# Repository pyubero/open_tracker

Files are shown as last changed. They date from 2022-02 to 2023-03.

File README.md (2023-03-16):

# open_tracker

The `open_tracker` is a suite of Computer Vision scripts that automatizes the recording and analysis of *C. elegans* behavioral videos, although it can be used with any animal/object in general. It was developed by Pablo Yubero at the Centro Nacional de Biotecnología (CSIC) in Madrid, Spain for the completion of the doctoral thesis entitled "Trade-offs in the architecture and predictability of complex phenotypes" funded by the Ministerio de Ciencia e Innovación and the Europen Social Fund.

<p align="center">
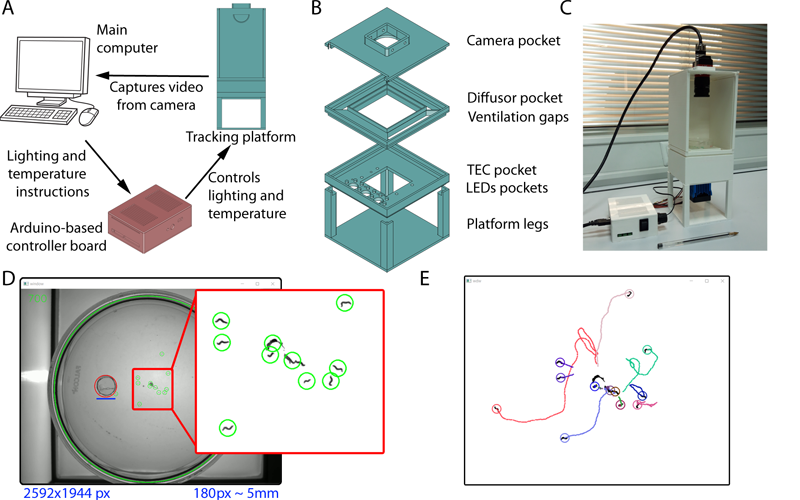
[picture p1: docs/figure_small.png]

</p>

## Protocol :bug:
The intended use of these scripts is sequential. I here include a brief description of each script.

* `s0_Recording.py` On execution, it will show a live preview of your camera stream, thus the user can easily adjust the lighting conditions, the focus of the camera and all that jazz before pressing "R" and starting to record a video. If the video is too long, the video will be recorded in fixed-length chunks (limits can be tuned). 
* `s1_Blob_extraction.py` On execution it will load a video, and do all the preprocessing to then export a pickle file with all the moving blobs found. If the results are not satisfactory, the user can easily tune all preprocessing steps. 
* `s2a_Ref_contour_finder.py` As worms are kind of small (to maximize field of view), they can sometimes be mixed up with noise. This scripts is aimed at identifying a model worm to later reliably identify worms in every frame. On execution you will be presented with the first frame and its blobs, you can loop through them until finding the "ideal worm" that will be used as reference. Once found, press "S" to save it, then "Q" to exit.
* `s2b_Metric_selection.py` On execution, it will analyse all blobs in the first frames of the videos to build a model (Gaussian Mixture) to automatically set up a metric that guarantees the correct identification of most (and best) worms.
* `s3_Tracking.py` This is the real deal, it will use all the previous data to finally export an .npz matrix  of size (n\_worms x n\_frames x 2) that stores the coordinates (x and y) of all worms in all frames, filled with np.nan's when necessary. 

## Materials and methods :telescope:
#### Image processing
For image processing we strongly recommend  using OpenCV, although we seldom use our own algorithms. OpenCV includes for example automatic background subtraction, complex shape/animal recognition, brightness and contrast control, thresholding, image denoising...

#### Tracking algorithm
The tracker is able to track a variable number of worms in any video, thus a predefined number is not necessary. At frame t+1, identity matching proceeds in four steps.

1. All worms present in frame t are matched by a progressive scanning algorithm and a Kalman filter, this facilitates the identification of worm forking, that is,when two initially superimposed worms separate).
2. The remaining worms are linked to blobs that are already in use to facilitate the identification of overlapping worms, that is, when two initially distinct worms touch each other). 
3. The remaining unused blobs are then candidates to be newly identified worms. Those are selected according to some user-defined rule, in our case, we used similarity of both Hu's invariant image descriptors and worm size.
4. (Optional) The tracking of some worms can be stopped. This can be used when worms can escape the field of view. 

#### Environmental control 
The environmental conditions are controlled by an Arduino Nano on a homemade controlling board. The board supports 3x high power LEDs (we are currently using the triplet 400nm, 650nm and 400K); a 60W Thermoelectric Couple that works in both heat/cold directions; 2x small fans to dissipate heat and accelerate cooling; automatic zoom/focus via two stepper motors (currently unused); two small indicating bicolor LEDs; and a temperature sensor.

#### Recording platform
The recording platform and a case for the controlling board were both designed using FreeCAD. Original and print-ready .stl files are available in the `/docs/models_3d` folder. All pieces were printed nicely using either ABS or PLA by standard protocols in a Ultimaker 2 printer. We strongly recommend using black (mate if possible) plastic to prevent leaks of light and internal reflections.

#### Webcam support
In this repo you will find support for two types of webcam, those that use the Universal Video Class (UVC) and those that rely on AppliedVision's Vimba SDK. While UVC works using OpenCV, AppliedVision's cameras need the Vimba SDK for Python installed.

There are different classes to interact with each type called `/pytracker/myCamera_UVC` and `/pytracker/myCamera_Alvium`, be sure to use the most appropiate one. These classes have a few fundamental functions: `open()`,`close()`,`snapshot()`,`start_preview()`, `get()`, and `set()`, you can find more info on how to use them in the scripts contained in the `\test` folder.

## Reference :bell:
Should you use this repo in any way, please reference the PhD thesis: 

Yubero P. (2022). _Trade-offs in the architecture and predictability of complex phenotypes_. (Doctoral dissertation, Universidad Autónoma de Madrid, Spain). Retrieved from repositorio.uam.es

## Contact and license :incoming_envelope:
If you have any issue with this repo please contact me through github rather than email. Feel free to ask for updated versions, or latest developments.

This code is distributed under an MIT license.

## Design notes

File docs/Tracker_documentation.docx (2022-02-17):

Worm Tracker Documentation

# Introduction

# Software

# Hardware

An arduino is a microprocessor that is able to perform simple tasks like turning on/off switches and measuring voltages. We will use this to precisly control three high power leds for illumination, a Peltier element (thermoelectric couple) and a couple of fans for temperature control and, a motor driver to digitally control the focus of the camera. Also, we use the Firmata protocol to establish a robust communication between the Arduino and a computer. In the following sections you can find a detailed description of why and how the controller board was designed.

### Arduino (in general)

We use an Arduino Nano board, because it has enough digital pins to control everything we need, it can be based on either ATmega168 or ATmega328. In general, it features several modules that will be described in the following sections namely: thermistor, manual potentiometer, led lighting, temperature control, stepper motor control and signaling leds (see Table X)

Pulldown resistors. When the Arduino is turned on, all pins are turned as input by default. During this time, digital pin values are floating and are neither high nor low. After a few seconds, all pins are set to output low [DO IN SOFTWARE]. To avoid this transient response, we have added to every digital output pin a pulldown resistor to keep this from happening.

<W> The Arduino board must necessarily share the ground connection with the external power supply at all times.

Number | Function | Pins | Comments
1 | Temperature sensor | A0 | Analog thermistor
1 | Potentiometer | A1 | Manual action
3 | Dimmable high power leds | D9, D10 and D11 | 1W, 350mA
1 | One-way TEC control (60W) | D5 | w/ MOSFET
1 | Two-way TEC control (60W) | D5 and D6 | w/ motor driver
1 | Fan control | D2 | Two fans in parallel
1 | Stepper motor control | D12 and D13 | Used to focus
1 | Signaling leds | D7 and D8 | Bicolor

Table 1. Main board functions

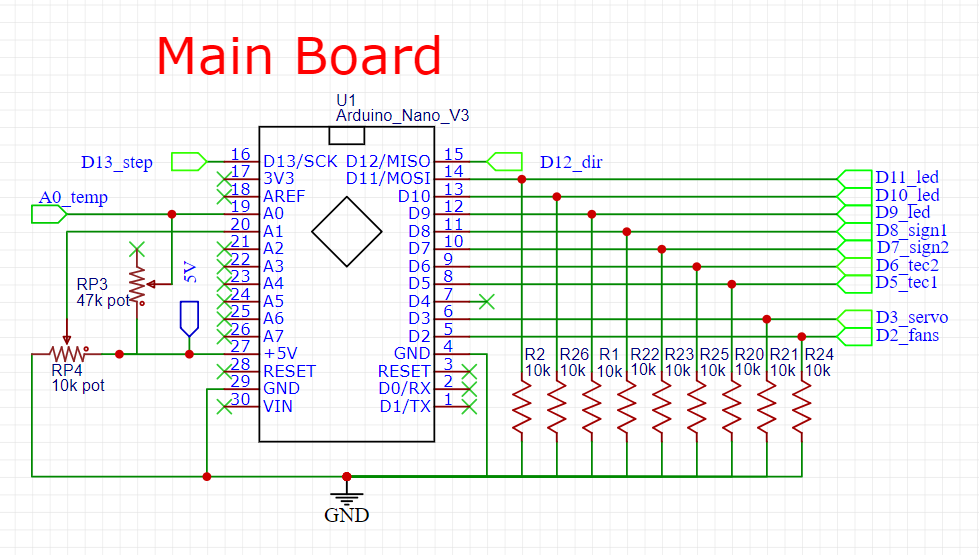
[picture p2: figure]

### Temperature sensor

We use a thermistor called an “3950 NTC Thermistor Temperature Sensor 10K 1%” with a beta parameter equal to 3380K +/- 1%. This device is a resistor whose value depends strongly on its temperature. As it is an N(egative)TC, when the temperature raises, the resistance falls. To compute the temperature we need two equations: one to compute the temperature of the probe from its resistance, and another to compute the resistance from an analog voltage (as measured by the Arduino).

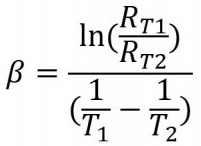
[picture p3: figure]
NTC Thermistor Beta Equation

First, the equation to the left can be rearranged to provide a resistance value (R_T2) given a temperature (T2) and a reference resistance (R_T1) at a reference temperature (T1). Note that temperatures are in Kelvin. The reference temperature T1 is usually 25ºC, or 298K. Its resistance at such temperature R_T1 is about 10kOhm, and the beta constant is said to be 3380 1/K. Plug everything into the equation and you can obtain T2 as a function of R2.

T_2 =((ln((R_2)/(R_1)))/β+1/(T_1))+293

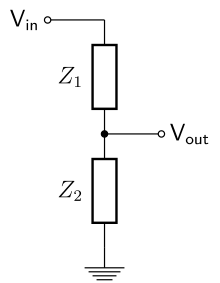
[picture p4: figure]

To measure R2, we use a voltage divider as the schematic in the left. Vin is a constant reference voltage (5V in our case), Z1 and Z2 are two resistors and Vout is the voltage measured at that point (A0 in our case). Either Z1 or Z2 can be a reference resistor and the other is the thermistor (as a variable resistor, R2 in the previous paragraph). The voltage measured in Vout, will be: Vout = Vin*(Z2/[Z1+Z2]). From this equation, one can obtain a function that returns the variable resistance R2 as a function of the measured voltage Vout. Depending on your reference resistor, temperature will be measured more accurately in a certain range of temperatures. We recommend a reference resistance equal to the NTC resistance at around 20ºC to maximize precision at this temperature. On top of this, Arduino does not directly measure Vout, but rather, the fraction Vout/Vin in 8bit. This means that when reading A0=0 then Vout=0V and when A0=256 then Vout=Vin. We finally have:

R_2 =R_(ref) ((V_(out))/(V −V_(out)))=R_(ref) ((A0)/(256−A0))

In our case we have used the scenario where Z1 is a 47kOhm variable resistor and Z2=R2. With this, we can adjust Z1 for improved temperature accuracy.

Note that the previous is a general procedure, but in our case, as we use the Firmata protocol to es

### Potentiometer (manual)

We have added a potentiometer that can be turned manually to make it easy to adjust the output of any pin. The goal was to easily dim the principal led, but other functions can be set in the myArduino class. The working principle is that of the voltage divider as in the previous section, in this case however Z1+Z2 is fixed to the potentiometer’s maximum value (10kOhm in our circuit).

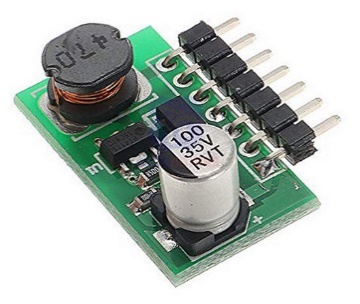
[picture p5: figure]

### Dimmable high power leds

The Arduino board cannot output over 40mA in a single pin, hence, to drive high power leds that require 350mA we need a led driver. We use a cheap module that allows to easily dim the led’s brightness with a PWM signal. A PWM signal is similar to an analog voltage that can take a continuum of values, in this way, the higher the voltage, the more intense the lighting.

For each high power led, we use either digital pins D9, D10 or D11. We have included a 4.7 kOhm resistor to limit the current provided by the Arduino to about 1mA. Also, we have tuned the fermata script to increase the frequency of the PWM signals driving the leds to avoid resonance with the camera FPS.

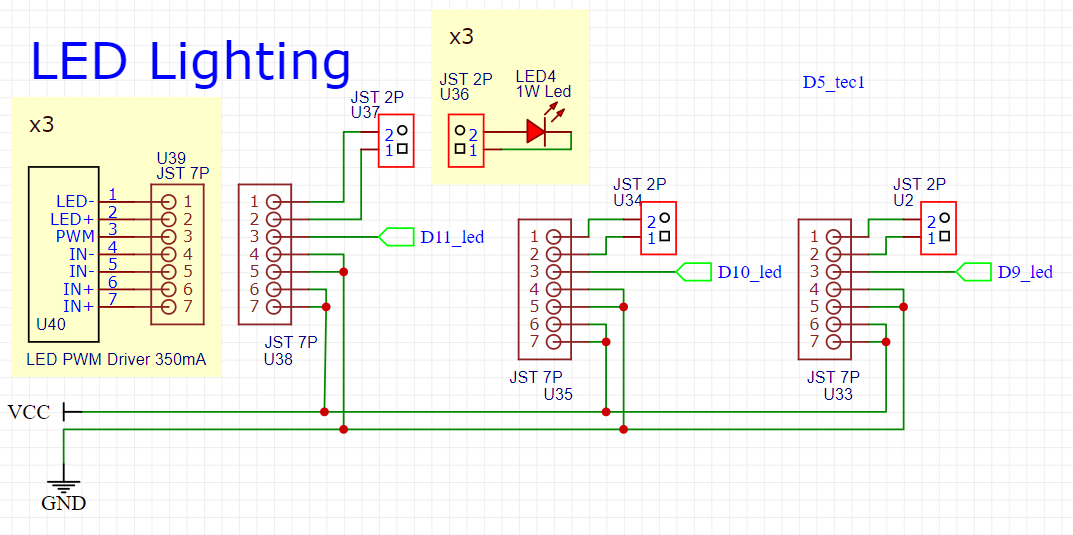
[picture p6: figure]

### TEC control

To control the temperature inside the chamber we use a “thermoelectric couple”, or TEC, also known as “Peltier element”. This device can cool down one of its faces and heat up the other while current is flowing. If the heat of the hot side is well dissipated, then the cold side can reach very low temperatures.

<W> It is very important that there is thermal paste between the TEC and both heat dissipators.

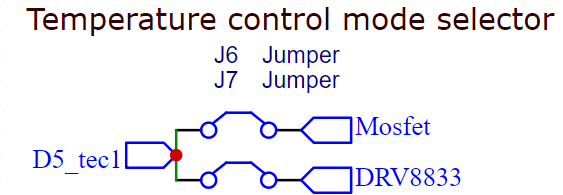
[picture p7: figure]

In our case we use a Peltier element rated max at 12V or 5A. The measured resistance is indeed about 2.5 ohm, but it can vary largely with temperature (or current). There is no easy and perfect way to control a TEC, so we propose two options: a one-way control that is only able to cool down the chamber (to hopefully very low temperatures) and a two-way control that is also able to heat up the chamber.

<W> To select between one- or two-way modes, we added a pair of jumpers. ONLY one should always be connected.

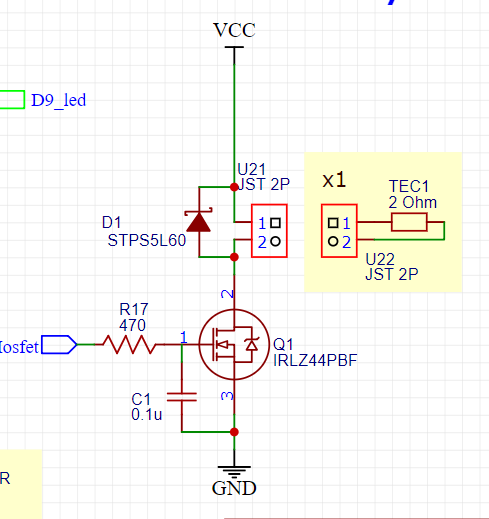
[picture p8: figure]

#### One-way control of the TEC

To drive the TEC at different voltages we will use a logic-level, switching MOSFET. By doing this, we can apply a PWM signal to the MOSFET’s gate to quickly turn it on/off so that the TEC sees a fraction of the total input voltage. If the duty cycle is set to 100% then around 4.5A will be going through the TEC providing a large cooling power but not efficiently! Recall that resistive power losses go as the current squared.

We chose the IRLZ44 due to its large voltage headroom (60V) for possible switching spikes and for its low R_DS=28mOhm. In the worst case scenario, 5A will go through the MOSFET, which will need to dissipate <1W. Even so, we can add a TO-220 dissipator. In the circuit we simply added a 470 Ohm resistor between the Arduino pin and the gate to limit the current to 10mA (and to protect the Arduino from back emf during switching). As the TEC is a resistive load, we shouldn’t need a flyback diode, however we attached one just in case parasitic inductance causes problems. We also added a decoupling cap between the gate and the ground.

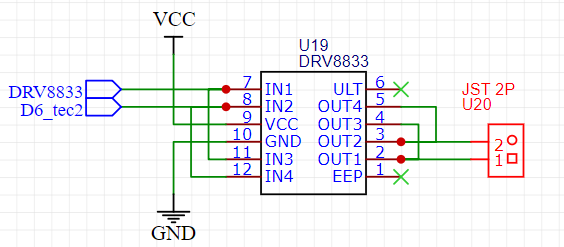
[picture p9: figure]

#### Two-way control of the TEC

To drive the TEC in both cold and hot modes, we must use the H-bridge of a motor driver. We used DRV8833 because of its relatively high output power (up to 1.5A per channel, so a total max of 3A which is less than the 4.5A of the one-way MOSFET). The module already includes different types of protection (over-temperature, over-current…) so the pinout is pretty straightforward. Depending on the IN1 and IN2 values cooling/heating modes are toggled. In our case IN1/3 are set by D6 while IN2/4 by D5. Remember that to turn off the Peltier module BOTH D5 and D6 need to be set LOW or HIGH.

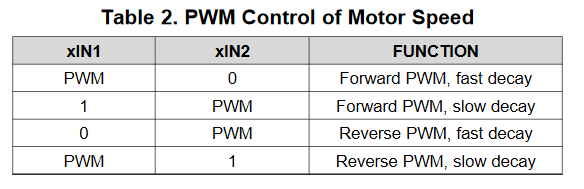
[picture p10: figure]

### Fan control

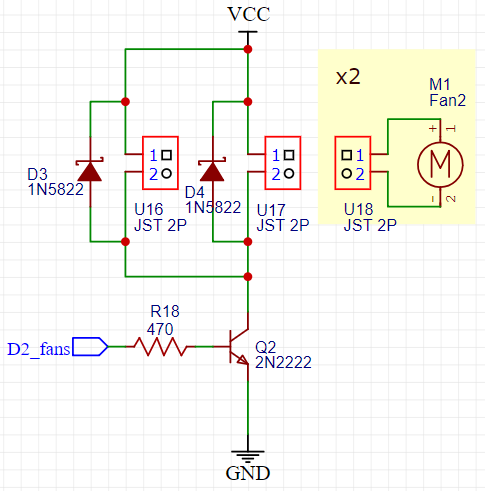
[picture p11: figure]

There should be TWO fans, one for the hot side and another for the cold side because i) the fan on the cold side will improve cooling power to the chamber, and ii) the fan on the cold side might be needed if the TEC direction is reversed and it starts heating the chamber.

Both fans are controlled with a 2N222 transistor as the necessary current is about 400mA (300mA from the large fan and an extra 100mA from the smaller one inside the chamber). Although fans have supposedly built-in flyback diodes, we added a pair of 1N5822 Schottkys (although they won’t be PWMed) for back EMF protection. There is also a 470 Ohm between the Arduino pin and the transistor’s base to limit the current to 10mA. With an hFE of 40 it results in about 400mA max across the collector and emitter. This transistor won’t be PWMed but rather we will fully turn it on/off for long periods of time.

### Stepper motor control

We add the possibility of controlling a stepper motor as an electronic camera focuser. However only x3 2P connectors are provided in the board as the A4988 stepper driver wouldn’t fit. Hence this optional module should be mounted on an external board.

Its connection is straightforward following any stepper tutorial. Mainly, we need a power connection (to power the motor), a logic power connection (to power the module) and two control signals: STEP and DIRECTION. We also propose to use three jumpers to select microstepping operation. Finally, a decoupling capacitor of 100nF is added between Vmot and GND.

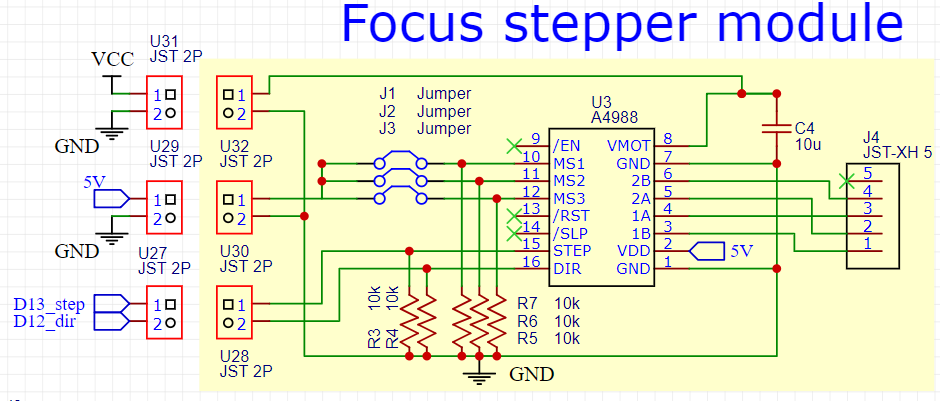
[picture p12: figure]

https://www.ti.com/lit/ds/symlink/drv8873-q1.pdf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

https://www.ti.com/lit/an/slua979a/slua979a.pdf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

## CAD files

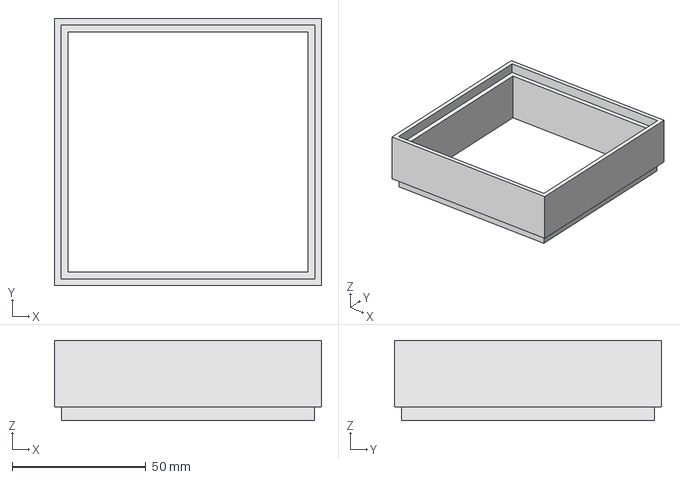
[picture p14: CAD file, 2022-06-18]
docs/models_3d/parametrized.FCStd
100.0 x 100.0 x 30.0 mm

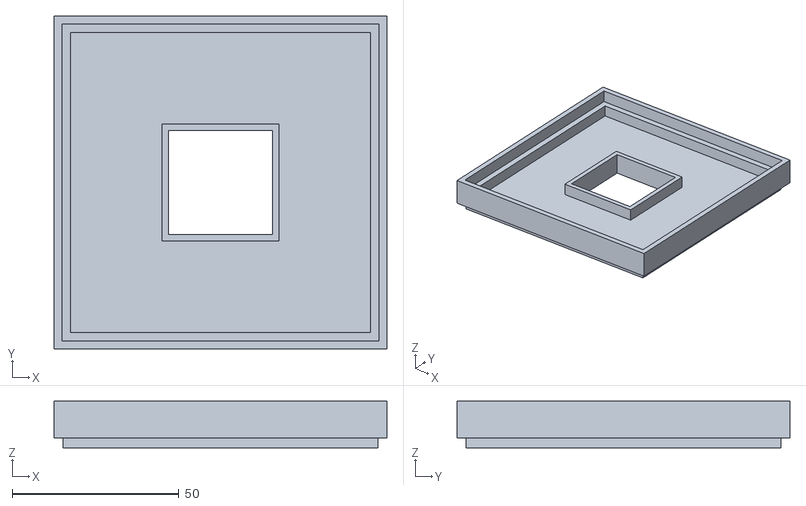
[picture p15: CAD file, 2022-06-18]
docs/models_3d/stl-files/parametrized-base_ledmatrix.stl
100.0 x 100.0 x 14.0

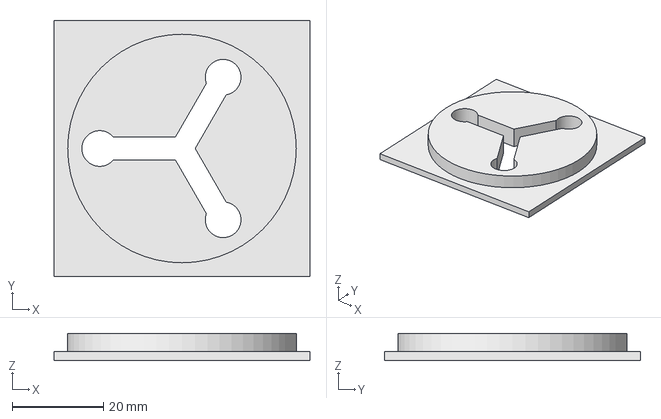
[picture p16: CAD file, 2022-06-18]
docs/models_3d/arenas.FCStd
56.0 x 56.0 x 6.00 mm

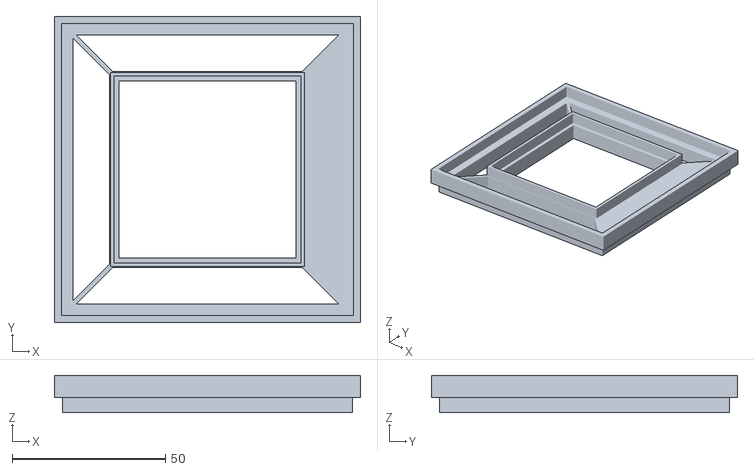
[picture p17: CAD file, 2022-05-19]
docs/models_3d/stl-files/parametrized-plate_base_v0.stl
100.0 x 100.0 x 12.1

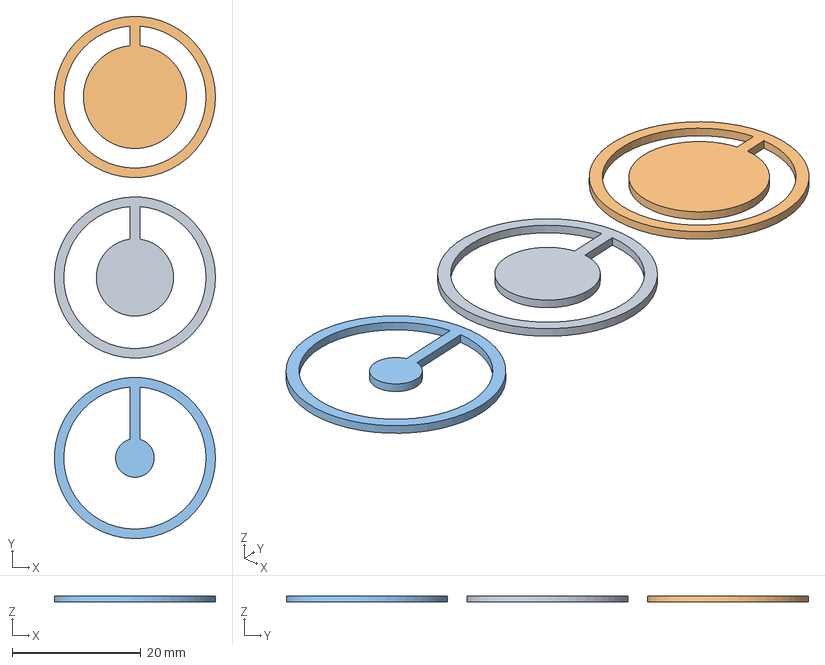
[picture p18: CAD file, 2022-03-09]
docs/models_3d/phase_shifters.FCStd
25.0 x 81.0 x 1.00 mm
shifter_medium
shifter_large
shifter_small

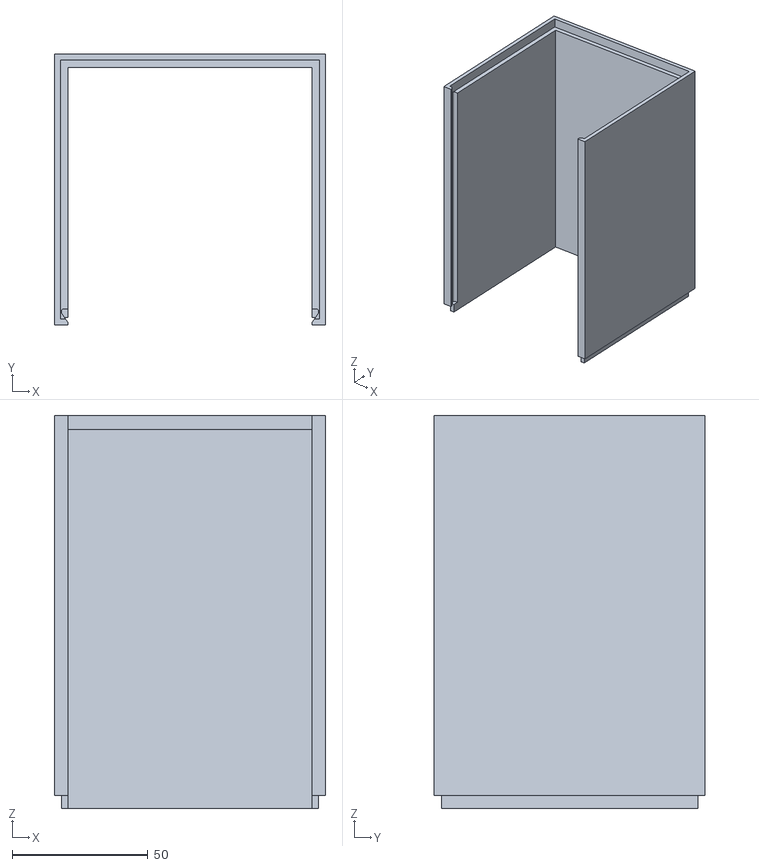
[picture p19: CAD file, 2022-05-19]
docs/models_3d/stl-files/Finished/parametrized-3walls_v1.stl
100.0 x 100.0 x 144.9

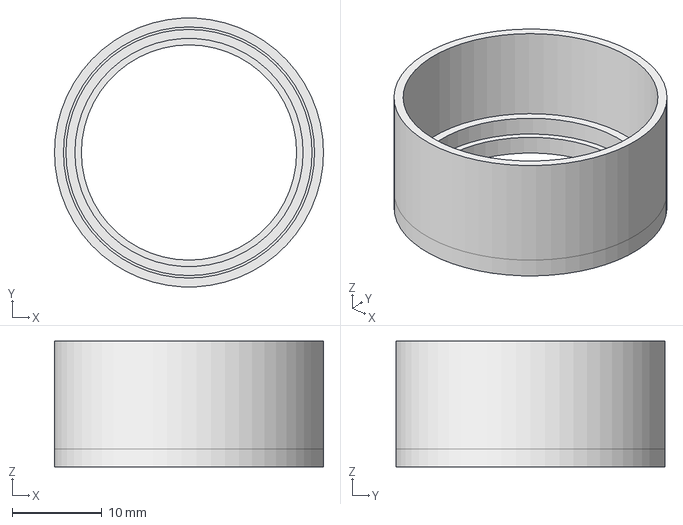
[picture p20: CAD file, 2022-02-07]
docs/models_3d/filter_holder.FCStd
30.0 x 30.0 x 14.0 mm

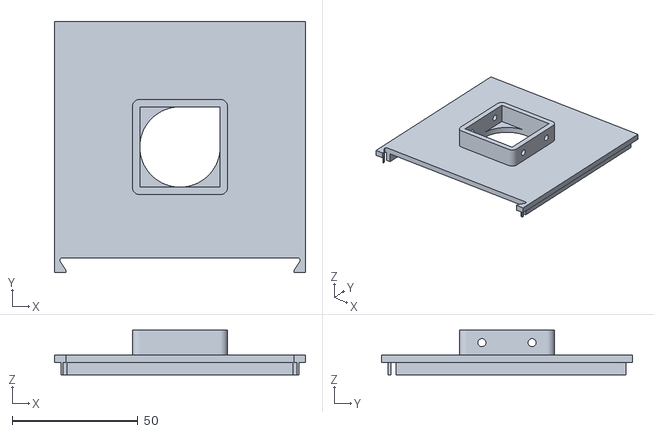
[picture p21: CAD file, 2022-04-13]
docs/models_3d/stl-files/Finished/parametrized-tapa_alvium_v1.stl
100.0 x 100.0 x 17.9

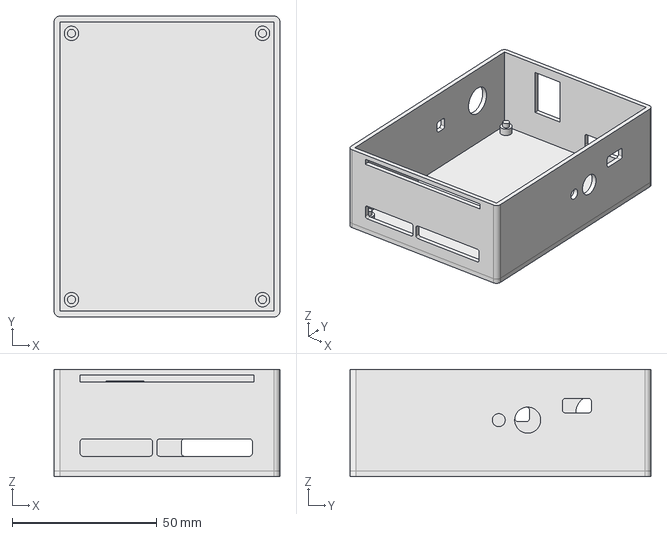
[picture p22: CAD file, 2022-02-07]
docs/models_3d/board_enclosure.FCStd
78.0 x 104.0 x 37.0 mm

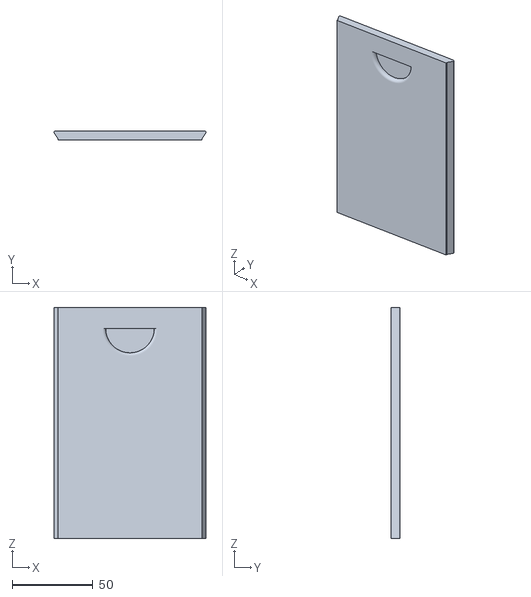
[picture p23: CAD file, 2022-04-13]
docs/models_3d/stl-files/Finished/parametrized-door.stl
94.0 x 5.85 x 143.0

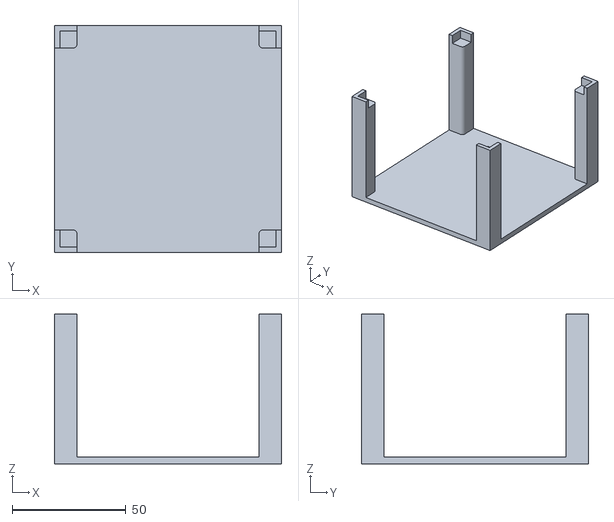
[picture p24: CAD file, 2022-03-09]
docs/models_3d/stl-files/Finished/parametrized-base_legs.stl
100.0 x 100.0 x 66.0

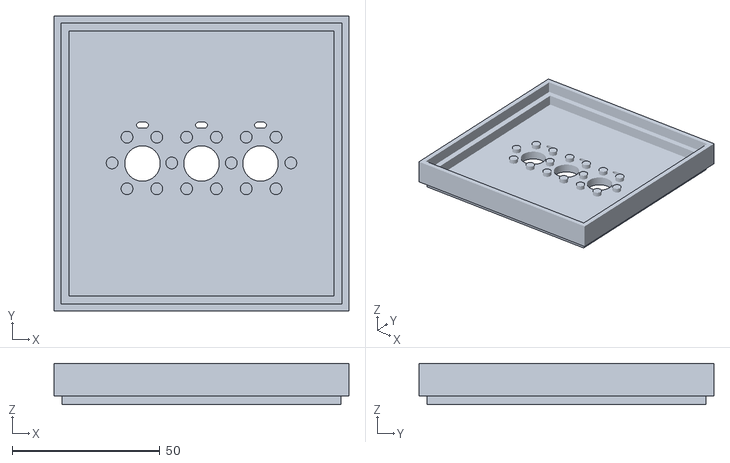
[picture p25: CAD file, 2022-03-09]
docs/models_3d/stl-files/Finished/base_lighting.stl
100.0 x 100.0 x 14.0

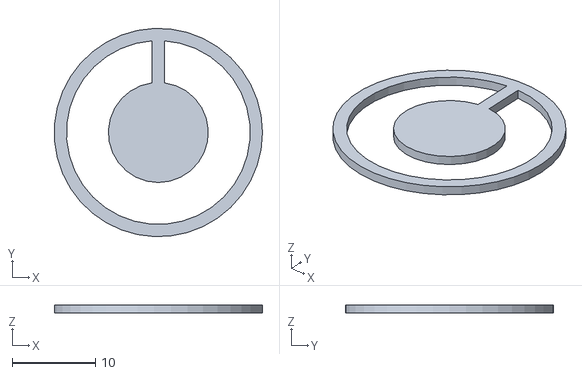
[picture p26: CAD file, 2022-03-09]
docs/models_3d/stl-files/Finished/phase_shifters-shifter_medium.stl
25.0 x 25.0 x 1.00

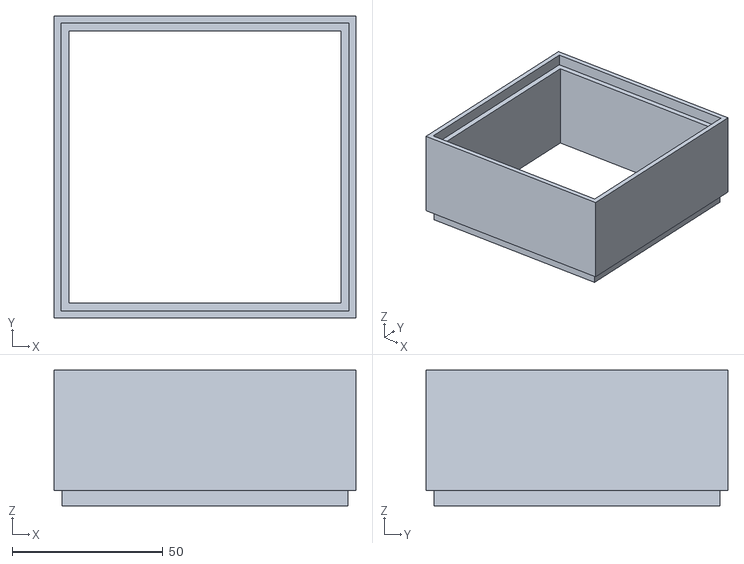
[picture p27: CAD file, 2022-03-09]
docs/models_3d/stl-files/Finished/parametrized-4walls_45mm.stl
100.0 x 100.0 x 45.0

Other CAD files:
docs/models_3d/stl-files/Finished/parametrized-4walls_30mm.stl
docs/models_3d/stl-files/Finished/arenas-2-decision_making.stl
docs/models_3d/stl-files/Finished/phase_shifters-shifter_small.stl
docs/models_3d/stl-files/Finished/tapon_led_update1.stl
docs/models_3d/stl-files/Finished/phase_shifters-shifter_large.stl

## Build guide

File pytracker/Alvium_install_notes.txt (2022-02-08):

Step 1.
Go to Allied Vision Download center to download the SDK.
In our case we installed v5.1.0 for Windows from:
	https://www.alliedvision.com/en/support/software-downloads/

Install on: C:\Program Files\Allied Vision\Vimba_5.1
and examples in : C:\Users\Public\Documents\Allied Vision\Vimba_5.1

And BE SURE to install the Python Api, although we recommend a complete installation of the SDK.

Step 2.
Go the C:\Program Files\Allied Vision\Vimba_5.1\VimbaPython\Documentation
and follow the manual's instructions for installing the python package.

Basically they say to execute from a (conda) terminal in the sources folder the following command: python -m pip install .[numpy-export,opencv-export]

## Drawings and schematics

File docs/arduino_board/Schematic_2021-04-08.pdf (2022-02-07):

VIN 30 GND 29 RESET 28 +5V 27 A7 26 A6 25 A5 24 A4 23 A3 22 A2 21 A1 20 A0 19 AREF 18 3V3 17 D13/SCK 16

# Main Board

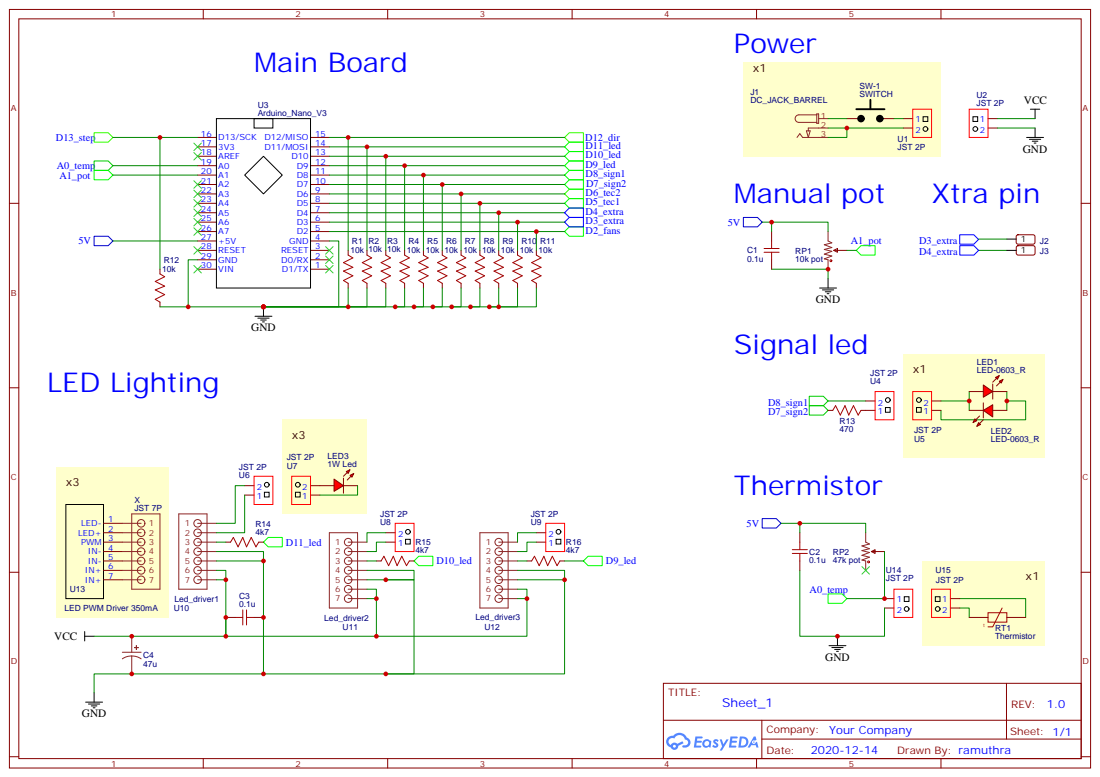
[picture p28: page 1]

# Focus stepper module

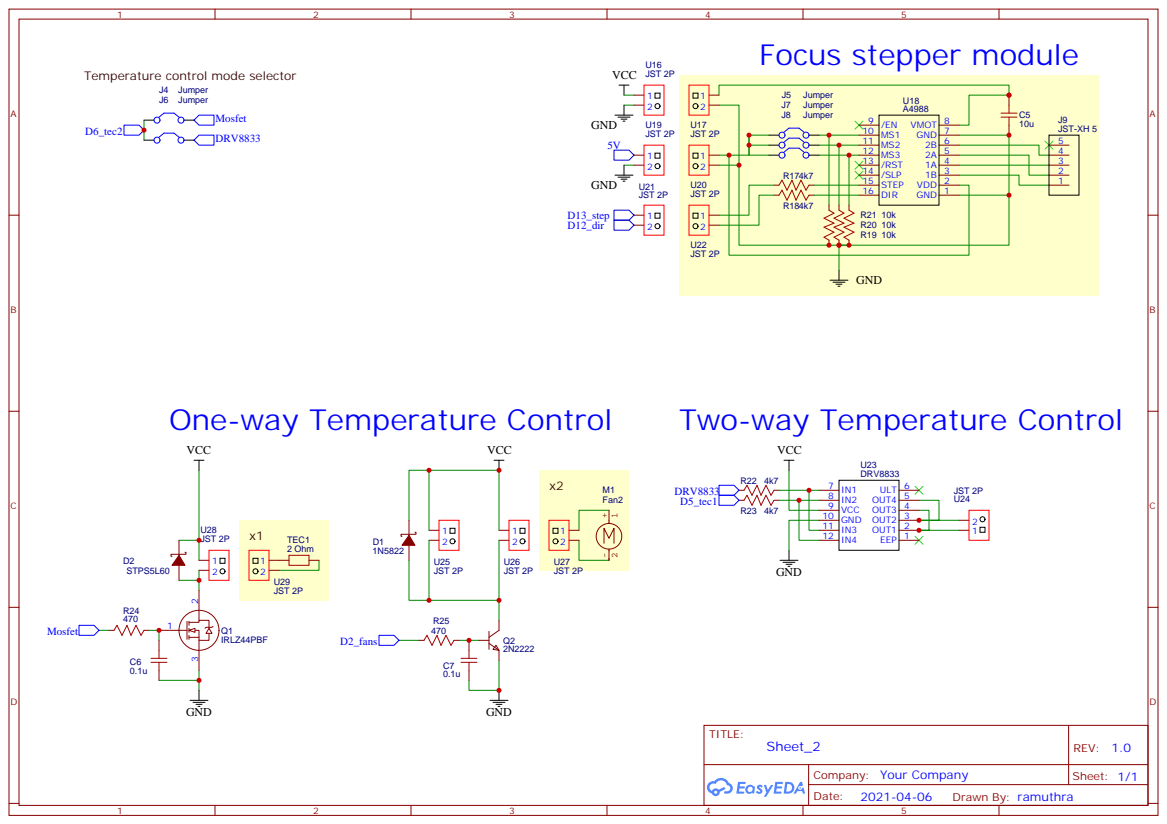
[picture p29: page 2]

Temperature control mode selector

One-way Temperature Control

Two-way Temperature Control

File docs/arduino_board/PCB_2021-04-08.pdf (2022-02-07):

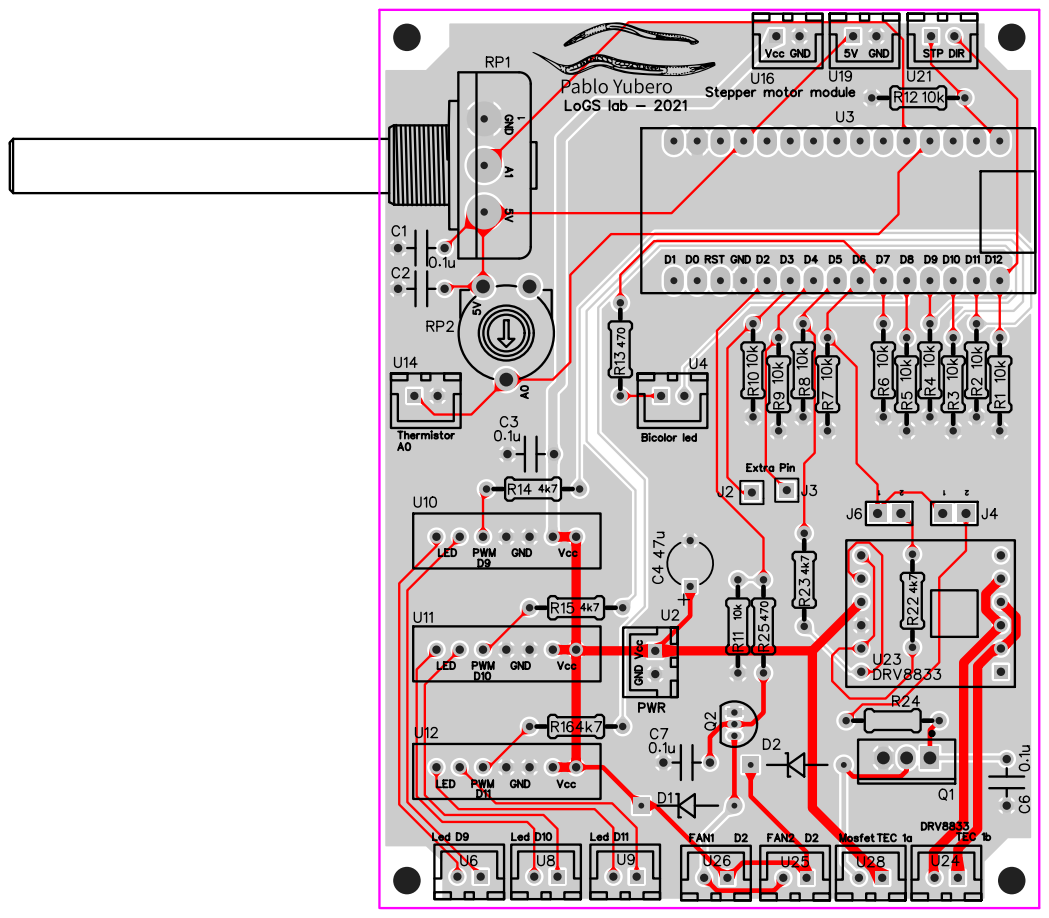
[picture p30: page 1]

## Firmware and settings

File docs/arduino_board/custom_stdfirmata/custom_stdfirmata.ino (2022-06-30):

/*
  Firmata is a generic protocol for communicating with microcontrollers
  from software on a host computer. It is intended to work with
  any host computer software package.

  To download a host software package, please click on the following link
  to open the list of Firmata client libraries in your default browser.

  https://github.com/firmata/arduino#firmata-client-libraries

  Copyright (C) 2006-2008 Hans-Christoph Steiner.  All rights reserved.
  Copyright (C) 2010-2011 Paul Stoffregen.  All rights reserved.
  Copyright (C) 2009 Shigeru Kobayashi.  All rights reserved.
  Copyright (C) 2009-2016 Jeff Hoefs.  All rights reserved.

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
  See file LICENSE.txt for further informations on licensing terms.

  Last updated August 17th, 2017

 This is a modified FIRMATA protocol. The only modifications being:
 1. The change of clock registers to allow faster PWM frequencies. 
 2. The change of serial Baudrate to minimize serial errors
 All changes reside in the ## SETUP ## section, around l. 750.

 - Pablo Yubero, January 2022 at the LoGS lab in Madrid.
*/

#include <Servo.h>
#include <Wire.h>
#include <Firmata.h>

#define I2C_WRITE                   B00000000
#define I2C_READ                    B00001000
#define I2C_READ_CONTINUOUSLY       B00010000
#define I2C_STOP_READING            B00011000
#define I2C_READ_WRITE_MODE_MASK    B00011000
#define I2C_10BIT_ADDRESS_MODE_MASK B00100000
#define I2C_END_TX_MASK             B01000000
#define I2C_STOP_TX                 1
#define I2C_RESTART_TX              0
#define I2C_MAX_QUERIES             8
#define I2C_REGISTER_NOT_SPECIFIED  -1

// the minimum interval for sampling analog input
#define MINIMUM_SAMPLING_INTERVAL   1


/*==============================================================================
 * GLOBAL VARIABLES
 *============================================================================*/

#ifdef FIRMATA_SERIAL_FEATURE
SerialFirmata serialFeature;
#endif

/* analog inputs */
int analogInputsToReport = 0; // bitwise array to store pin reporting

/* digital input ports */
byte reportPINs[TOTAL_PORTS];       // 1 = report this port, 0 = silence
byte previousPINs[TOTAL_PORTS];     // previous 8 bits sent

/* pins configuration */
byte portConfigInputs[TOTAL_PORTS]; // each bit: 1 = pin in INPUT, 0 = anything else

/* timer variables */
unsigned long currentMillis;        // store the current value from millis()
unsigned long previousMillis;       // for comparison with currentMillis
unsigned int samplingInterval = 19; // how often to run the main loop (in ms)

/* i2c data */
struct i2c_device_info {
  byte addr;
  int reg;
  byte bytes;
  byte stopTX;
};

/* for i2c read continuous more */
i2c_device_info query[I2C_MAX_QUERIES];

byte i2cRxData[64];
boolean isI2CEnabled = false;
signed char queryIndex = -1;
// default delay time between i2c read request and Wire.requestFrom()
unsigned int i2cReadDelayTime = 0;

Servo servos[MAX_SERVOS];
byte servoPinMap[TOTAL_PINS];
byte detachedServos[MAX_SERVOS];
byte detachedServoCount = 0;
byte servoCount = 0;

boolean isResetting = false;

// Forward declare a few functions to avoid compiler errors with older versions
// of the Arduino IDE.
void setPinModeCallback(byte, int);
void reportAnalogCallback(byte analogPin, int value);
void sysexCallback(byte, byte, byte*);

/* utility functions */
void wireWrite(byte data)
{
#if ARDUINO >= 100
  Wire.write((byte)data);
#else
  Wire.send(data);
#endif
}

byte wireRead(void)
{
#if ARDUINO >= 100
  return Wire.read();
#else
  return Wire.receive();
#endif
}

/*==============================================================================
 * FUNCTIONS
 *============================================================================*/

void attachServo(byte pin, int minPulse, int maxPulse)
{
  if (servoCount < MAX_SERVOS) {
    // reuse indexes of detached servos until all have been reallocated
    if (detachedServoCount > 0) {
      servoPinMap[pin] = detachedServos[detachedServoCount - 1];
      if (detachedServoCount > 0) detachedServoCount--;
    } else {
      servoPinMap[pin] = servoCount;
      servoCount++;
    }
    if (minPulse > 0 && maxPulse > 0) {
      servos[servoPinMap[pin]].attach(PIN_TO_DIGITAL(pin), minPulse, maxPulse);
    } else {
      servos[servoPinMap[pin]].attach(PIN_TO_DIGITAL(pin));
    }
  } else {
    Firmata.sendString("Max servos attached");
  }
}

void detachServo(byte pin)
{
  servos[servoPinMap[pin]].detach();
  // if we're detaching the last servo, decrement the count
  // otherwise store the index of the detached servo
  if (servoPinMap[pin] == servoCount && servoCount > 0) {
    servoCount--;
  } else if (servoCount > 0) {
    // keep track of detached servos because we want to reuse their indexes
    // before incrementing the count of attached servos
    detachedServoCount++;
    detachedServos[detachedServoCount - 1] = servoPinMap[pin];
  }

  servoPinMap[pin] = 255;
}

void enableI2CPins()
{
  byte i;
  // is there a faster way to do this? would probaby require importing
  // Arduino.h to get SCL and SDA pins
  for (i = 0; i < TOTAL_PINS; i++) {
    if (IS_PIN_I2C(i)) {
      // mark pins as i2c so they are ignore in non i2c data requests
      setPinModeCallback(i, PIN_MODE_I2C);
    }
  }

  isI2CEnabled = true;

  Wire.begin();
}

/* disable the i2c pins so they can be used for other functions */
void disableI2CPins() {
  isI2CEnabled = false;
  // disable read continuous mode for all devices
  queryIndex = -1;
}

void readAndReportData(byte address, int theRegister, byte numBytes, byte stopTX) {
  // allow I2C requests that don't require a register read
  // for example, some devices using an interrupt pin to signify new data available
  // do not always require the register read so upon interrupt you call Wire.requestFrom()
  if (theRegister != I2C_REGISTER_NOT_SPECIFIED) {
    Wire.beginTransmission(address);
    wireWrite((byte)theRegister);
    Wire.endTransmission(stopTX); // default = true
    // do not set a value of 0
    if (i2cReadDelayTime > 0) {
      // delay is necessary for some devices such as WiiNunchuck
      delayMicroseconds(i2cReadDelayTime);
    }
  } else {
    theRegister = 0;  // fill the register with a dummy value
  }

  Wire.requestFrom(address, numBytes);  // all bytes are returned in requestFrom

  // check to be sure correct number of bytes were returned by slave
  if (numBytes < Wire.available()) {
    Firmata.sendString("I2C: Too many bytes received");
  } else if (numBytes > Wire.available()) {
    Firmata.sendString("I2C: Too few bytes received");
  }

  i2cRxData[0] = address;
  i2cRxData[1] = theRegister;

  for (int i = 0; i < numBytes && Wire.available(); i++) {
    i2cRxData[2 + i] = wireRead();
  }

  // send slave address, register and received bytes
  Firmata.sendSysex(SYSEX_I2C_REPLY, numBytes + 2, i2cRxData);
}

void outputPort(byte portNumber, byte portValue, byte forceSend)
{
  // pins not configured as INPUT are cleared to zeros
  portValue = portValue & portConfigInputs[portNumber];
  // only send if the value is different than previously sent
  if (forceSend || previousPINs[portNumber] != portValue) {
    Firmata.sendDigitalPort(portNumber, portValue);
    previousPINs[portNumber] = portValue;
  }
}

/* -----------------------------------------------------------------------------
 * check all the active digital inputs for change of state, then add any events
 * to the Serial output queue using Serial.print() */
void checkDigitalInputs(void)
{
  /* Using non-looping code allows constants to be given to readPort().
   * The compiler will apply substantial optimizations if the inputs
   * to readPort() are compile-time constants. */
  if (TOTAL_PORTS > 0 && reportPINs[0]) outputPort(0, readPort(0, portConfigInputs[0]), false);
  if (TOTAL_PORTS > 1 && reportPINs[1]) outputPort(1, readPort(1, portConfigInputs[1]), false);
  if (TOTAL_PORTS > 2 && reportPINs[2]) outputPort(2, readPort(2, portConfigInputs[2]), false);
  if (TOTAL_PORTS > 3 && reportPINs[3]) outputPort(3, readPort(3, portConfigInputs[3]), false);
  if (TOTAL_PORTS > 4 && reportPINs[4]) outputPort(4, readPort(4, portConfigInputs[4]), false);
  if (TOTAL_PORTS > 5 && reportPINs[5]) outputPort(5, readPort(5, portConfigInputs[5]), false);
  if (TOTAL_PORTS > 6 && reportPINs[6]) outputPort(6, readPort(6, portConfigInputs[6]), false);
  if (TOTAL_PORTS > 7 && reportPINs[7]) outputPort(7, readPort(7, portConfigInputs[7]), false);
  if (TOTAL_PORTS > 8 && reportPINs[8]) outputPort(8, readPort(8, portConfigInputs[8]), false);
  if (TOTAL_PORTS > 9 && reportPINs[9]) outputPort(9, readPort(9, portConfigInputs[9]), false);
  if (TOTAL_PORTS > 10 && reportPINs[10]) outputPort(10, readPort(10, portConfigInputs[10]), false);
  if (TOTAL_PORTS > 11 && reportPINs[11]) outputPort(11, readPort(11, portConfigInputs[11]), false);
  if (TOTAL_PORTS > 12 && reportPINs[12]) outputPort(12, readPort(12, portConfigInputs[12]), false);
  if (TOTAL_PORTS > 13 && reportPINs[13]) outputPort(13, readPort(13, portConfigInputs[13]), false);
  if (TOTAL_PORTS > 14 && reportPINs[14]) outputPort(14, readPort(14, portConfigInputs[14]), false);
  if (TOTAL_PORTS > 15 && reportPINs[15]) outputPort(15, readPort(15, portConfigInputs[15]), false);
}

// -----------------------------------------------------------------------------
/* sets the pin mode to the correct state and sets the relevant bits in the
 * two bit-arrays that track Digital I/O and PWM status
 */
void setPinModeCallback(byte pin, int mode)
{
  if (Firmata.getPinMode(pin) == PIN_MODE_IGNORE)
    return;

  if (Firmata.getPinMode(pin) == PIN_MODE_I2C && isI2CEnabled && mode != PIN_MODE_I2C) {
    // disable i2c so pins can be used for other functions
    // the following if statements should reconfigure the pins properly
    disableI2CPins();
  }
  if (IS_PIN_DIGITAL(pin) && mode != PIN_MODE_SERVO) {
    if (servoPinMap[pin] < MAX_SERVOS && servos[servoPinMap[pin]].attached()) {
      detachServo(pin);
    }
  }
  if (IS_PIN_ANALOG(pin)) {
    reportAnalogCallback(PIN_TO_ANALOG(pin), mode == PIN_MODE_ANALOG ? 1 : 0); // turn on/off reporting
  }
  if (IS_PIN_DIGITAL(pin)) {
    if (mode == INPUT || mode == PIN_MODE_PULLUP) {
      portConfigInputs[pin / 8] |= (1 << (pin & 7));
    } else {
      portConfigInputs[pin / 8] &= ~(1 << (pin & 7));
    }
  }
  Firmata.setPinState(pin, 0);
  switch (mode) {
    case PIN_MODE_ANALOG:
      if (IS_PIN_ANALOG(pin)) {
        if (IS_PIN_DIGITAL(pin)) {
          pinMode(PIN_TO_DIGITAL(pin), INPUT);    // disable output driver
#if ARDUINO <= 100
          // deprecated since Arduino 1.0.1 - TODO: drop support in Firmata 2.6
          digitalWrite(PIN_TO_DIGITAL(pin), LOW); // disable internal pull-ups
#endif
        }
        Firmata.setPinMode(pin, PIN_MODE_ANALOG);
      }
      break;
    case INPUT:
      if (IS_PIN_DIGITAL(pin)) {
        pinMode(PIN_TO_DIGITAL(pin), INPUT);    // disable output driver
#if ARDUINO <= 100
        // deprecated since Arduino 1.0.1 - TODO: drop support in Firmata 2.6
        digitalWrite(PIN_TO_DIGITAL(pin), LOW); // disable internal pull-ups
#endif
        Firmata.setPinMode(pin, INPUT);
      }
      break;
    case PIN_MODE_PULLUP:
      if (IS_PIN_DIGITAL(pin)) {
        pinMode(PIN_TO_DIGITAL(pin), INPUT_PULLUP);
        Firmata.setPinMode(pin, PIN_MODE_PULLUP);
        Firmata.setPinState(pin, 1);
      }
      break;
    case OUTPUT:
      if (IS_PIN_DIGITAL(pin)) {
        if (Firmata.getPinMode(pin) == PIN_MODE_PWM) {
          // Disable PWM if pin mode was previously set to PWM.
          digitalWrite(PIN_TO_DIGITAL(pin), LOW);
        }
        pinMode(PIN_TO_DIGITAL(pin), OUTPUT);
        Firmata.setPinMode(pin, OUTPUT);
      }
      break;
    case PIN_MODE_PWM:
      if (IS_PIN_PWM(pin)) {
        pinMode(PIN_TO_PWM(pin), OUTPUT);
        analogWrite(PIN_TO_PWM(pin), 0);
        Firmata.setPinMode(pin, PIN_MODE_PWM);
      }
      break;
    case PIN_MODE_SERVO:
      if (IS_PIN_DIGITAL(pin)) {
        Firmata.setPinMode(pin, PIN_MODE_SERVO);
        if (servoPinMap[pin] == 255 || !servos[servoPinMap[pin]].attached()) {
          // pass -1 for min and max pulse values to use default values set
          // by Servo library
          attachServo(pin, -1, -1);
        }
      }
      break;
    case PIN_MODE_I2C:
      if (IS_PIN_I2C(pin)) {
        // mark the pin as i2c
        // the user must call I2C_CONFIG to enable I2C for a device
        Firmata.setPinMode(pin, PIN_MODE_I2C);
      }
      break;
    case PIN_MODE_SERIAL:
#ifdef FIRMATA_SERIAL_FEATURE
      serialFeature.handlePinMode(pin, PIN_MODE_SERIAL);
#endif
      break;
    default:
      Firmata.sendString("Unknown pin mode"); // TODO: put error msgs in EEPROM
  }
  // TODO: save status to EEPROM here, if changed
}

/*
 * Sets the value of an individual pin. Useful if you want to set a pin value but
 * are not tracking the digital port state.
 * Can only be used on pins configured as OUTPUT.
 * Cannot be used to enable pull-ups on Digital INPUT pins.
 */
void setPinValueCallback(byte pin, int value)
{
  if (pin < TOTAL_PINS && IS_PIN_DIGITAL(pin)) {
    if (Firmata.getPinMode(pin) == OUTPUT) {
      Firmata.setPinState(pin, value);
      digitalWrite(PIN_TO_DIGITAL(pin), value);
    }
  }
}

void analogWriteCallback(byte pin, int value)
{
  if (pin < TOTAL_PINS) {
    switch (Firmata.getPinMode(pin)) {
      case PIN_MODE_SERVO:
        if (IS_PIN_DIGITAL(pin))
          servos[servoPinMap[pin]].write(value);
        Firmata.setPinState(pin, value);
        break;
      case PIN_MODE_PWM:
        if (IS_PIN_PWM(pin))
          analogWrite(PIN_TO_PWM(pin), value);
        Firmata.setPinState(pin, value);
        break;
    }
  }
}

void digitalWriteCallback(byte port, int value)
{
  byte pin, lastPin, pinValue, mask = 1, pinWriteMask = 0;

  if (port < TOTAL_PORTS) {
    // create a mask of the pins on this port that are writable.
    lastPin = port * 8 + 8;
    if (lastPin > TOTAL_PINS) lastPin = TOTAL_PINS;
    for (pin = port * 8; pin < lastPin; pin++) {
      // do not disturb non-digital pins (eg, Rx & Tx)
      if (IS_PIN_DIGITAL(pin)) {
        // do not touch pins in PWM, ANALOG, SERVO or other modes
        if (Firmata.getPinMode(pin) == OUTPUT || Firmata.getPinMode(pin) == INPUT) {
          pinValue = ((byte)value & mask) ? 1 : 0;
          if (Firmata.getPinMode(pin) == OUTPUT) {
            pinWriteMask |= mask;
          } else if (Firmata.getPinMode(pin) == INPUT && pinValue == 1 && Firmata.getPinState(pin) != 1) {
            // only handle INPUT here for backwards compatibility
#if ARDUINO > 100
            pinMode(pin, INPUT_PULLUP);
#else
            // only write to the INPUT pin to enable pullups if Arduino v1.0.0 or earlier
            pinWriteMask |= mask;
#endif
          }
          Firmata.setPinState(pin, pinValue);
        }
      }
      mask = mask << 1;
    }
    writePort(port, (byte)value, pinWriteMask);
  }
}


// -----------------------------------------------------------------------------
/* sets bits in a bit array (int) to toggle the reporting of the analogIns
 */
//void FirmataClass::setAnalogPinReporting(byte pin, byte state) {
//}
void reportAnalogCallback(byte analogPin, int value)
{
  if (analogPin < TOTAL_ANALOG_PINS) {
    if (value == 0) {
      analogInputsToReport = analogInputsToReport & ~ (1 << analogPin);
    } else {
      analogInputsToReport = analogInputsToReport | (1 << analogPin);
      // prevent during system reset or all analog pin values will be reported
      // which may report noise for unconnected analog pins
      if (!isResetting) {
        // Send pin value immediately. This is helpful when connected via
        // ethernet, wi-fi or bluetooth so pin states can be known upon
        // reconnecting.
        Firmata.sendAnalog(analogPin, analogRead(analogPin));
      }
    }
  }
  // TODO: save status to EEPROM here, if changed
}

void reportDigitalCallback(byte port, int value)
{
  if (port < TOTAL_PORTS) {
    reportPINs[port] = (byte)value;
    // Send port value immediately. This is helpful when connected via
    // ethernet, wi-fi or bluetooth so pin states can be known upon
    // reconnecting.
    if (value) outputPort(port, readPort(port, portConfigInputs[port]), true);
  }
  // do not disable analog reporting on these 8 pins, to allow some
  // pins used for digital, others analog.  Instead, allow both types
  // of reporting to be enabled, but check if the pin is configured
  // as analog when sampling the analog inputs.  Likewise, while
  // scanning digital pins, portConfigInputs will mask off values from any
  // pins configured as analog
}

/*==============================================================================
 * SYSEX-BASED commands
 *============================================================================*/
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
void loop()
{
  byte pin, analogPin;

  /* DIGITALREAD - as fast as possible, check for changes and output them to the
   * FTDI buffer using Serial.print()  */
  checkDigitalInputs();

  /* STREAMREAD - processing incoming messagse as soon as possible, while still
   * checking digital inputs.  */
  while (Firmata.available())
    Firmata.processInput();

  // TODO - ensure that Stream buffer doesn't go over 60 bytes

  currentMillis = millis();
  if (currentMillis - previousMillis > samplingInterval) {
    previousMillis += samplingInterval;
    /* ANALOGREAD - do all analogReads() at the configured sampling interval */
    for (pin = 0; pin < TOTAL_PINS; pin++) {
      if (IS_PIN_ANALOG(pin) && Firmata.getPinMode(pin) == PIN_MODE_ANALOG) {
        analogPin = PIN_TO_ANALOG(pin);
        if (analogInputsToReport & (1 << analogPin)) {
          Firmata.sendAnalog(analogPin, analogRead(analogPin));
        }
      }
    }
    // report i2c data for all device with read continuous mode enabled
    if (queryIndex > -1) {
      for (byte i = 0; i < queryIndex + 1; i++) {
        readAndReportData(query[i].addr, query[i].reg, query[i].bytes, query[i].stopTX);
      }
    }
  }

#ifdef FIRMATA_SERIAL_FEATURE
  serialFeature.update();
#endif
}

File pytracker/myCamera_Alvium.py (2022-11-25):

# -*- coding: utf-8 -*-
"""
Created on Wed Nov 10 14:26:05 2021

@author: Pablo
"""
import cv2
import numbers
import numpy as np
from vimba import *
from datetime import datetime
from time import sleep
from threading import Thread
from sys import platform
from matplotlib import pyplot as plt
from tqdm import tqdm

class myCamera:
    def __init__(self, camera_id = None, backend = cv2.CAP_DSHOW ):
        
        #...define initial variables
        self.camera_id = camera_id
        self.backend   = backend
        self.vcapture  = cv2.VideoCapture() # cap object is created but it is not assigned to any camera 
        
        self._verbose      = True
        self._is_open      = False
        self._frame        = []
        self._exposure_auto = False

        self.thread_streaming_running = False
        self.thread_recording_running = False
        self.preview_running          = False

        self.recording_filename = 'video_NVIDEO.avi'
        self.recording_format   = 'MJPG'
        self.recording_fps      = 1
        self.recording_totaltime= 99999 #about 2.7h
        self.recording_maxtime  = 5
        self.recording_nvideo   = 0
        
        
        # INITIALIZATION #
        if camera_id is not None:
            self.open( self.camera_id )
            # self.__update_properties() #called from within open()
            


        
    def __del__(self):
        self.close()


    def close(self):
        if self.thread_recording_running:
            self.stop_recording()
            
        if self.preview_running:
            self.stop_preview()
            
        if self.thread_streaming_running:
            self.stop_streaming()
                
        
        
    def open(self, camera_id = None):
        if camera_id is None:
            camera_id = self.camera_id
        else:
            self.camera_id = camera_id
            
        try:
            if self.thread_streaming_running:
                print('<< E >> Camera %d is already open.' % camera_id)
                return 
            
            with Vimba.get_instance() as vimba:
                cams = vimba.get_all_cameras()
                with cams[self.camera_id] as cam:
                    self.__update_properties(cam)
                    
            self._is_open = True
            print('Alvium camera %d can now be opened.' % camera_id )
            return True
        
        except:
            self._is_open = False
            print('<< E >> Failed to connect to Alvium camera %d.' % camera_id )
            return False
        
        
        
    def snapshot(self, formfactor = 1):
        # Slow way of taking pictures. It takes about 1s to open the camera and take a picture.
        # If you need taking pictures faster, we recommend to start a stream, and grab
        # pictures directly from self.frame.
        
        # A camera needs to be available
        if not self._is_open:
            print('<< E >> Please, open the camera before taking any snapshot.')
            return
        
        # If a stream is already running, return current frame
        if self.thread_streaming_running:
            pass
        #... if not, access the camera and update current frame
        else:
            with Vimba.get_instance() as vimba:
                cams = vimba.get_all_cameras()
                with cams[self.camera_id] as cam:
                    self.__set_properties(cam)
                    self.__update_properties(cam)
                    frame_alvium = cam.get_frame()
                    # frame_alvium.convert_pixel_format(PixelFormat.Mono8) # I think this is unnecessary
                    
                    self.frame = frame_alvium.as_opencv_image()
                    
        if formfactor != 1:    
            print('Snapshot taken and resized by %1.2f.' % formfactor ) if self._verbose else None
            return cv2.resize( self.frame , None , fx=formfactor , fy=formfactor)
        else:
            print('Snapshot taken.') if self._verbose else None
            return self.frame


    #################################
    ####### MODIFY PROPERTIES #######
    # To prevent the camera from raising errors from mismanipulations,
    # we create a copy of the supposed properties of the camera as a dict.
    # Whenever we use set() we JUST change the value in the dictionnary.
    # Then whenever the camera is opened (snapshot and streaming), we try to upload
    # ...the values from the dict to the camera. 
    # The true property values of the camera are downloaded whenever the camera 
    # ... is instantiated and after uploading our own values from the dict.
    
    def get(self, propertyName):
        if propertyName in self.properties:
            return self.properties[propertyName]
        else:
            print('<< W >> %s could not be found in myCamera.properties.' % propertyName )
            return False

    def set(self, propertyName, value):
        if propertyName in self.properties:
            self.properties.update( {propertyName : value})
            print('Changed %s to %s' % (propertyName, str(value)) )
        else:
            print('<< W >> %s could not be found in myCamera.properties.' % propertyName )
            return False
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

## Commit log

2022-02-08 Creation of camera test files
    Both test_camera_avlium and _uvc are now ready for definitive use.
2022-02-17 And we're rolling
    - myArduTracker() is now a self-sufficient class that no longer requires myArduino(). It now includes basic functions to modify led, tec and fan states, as well as reading the potentiometer and the thermistor. <W> both temperature control and potlink functions are UNTESTED.
    - a few test files are included to demonstrate the basic usage of an arduino board.
    [tec_test.csv]
2022-03-09 Updates of 3D models
    Main board: added a lighting-only base without space for the TEC or fans.
    Phase shifters: measures linked to spreadsheet; and measures updated.
    STL files: some are new, some have been moved to /Finished
    tec_test.csv now is called data_test_tec.csv for clarity.
    [base_lighting.stl, data_test_tec.csv, parametrized-4walls.stl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]
2022-03-26 Updated 3d models
    Improved covers for led holes and walling system
    [parametrized-3walls.stl, parametrized-4walls.stl, parametrized.FCStd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]
2022-03-26 Zoom and true_size support for Alvium cameras.
2022-03-28 Updated myCamera_Alvium
    Fixed error during automatic chunking of videos. Now it succesfully records videos of any length in samller chunks.
    [myCamera_Alvium.py]
2022-03-28 Update myCamera_UVC.py
    Fixed errors for automatic video chunking. Untested!
    [myCamera_UVC.py]
2022-04-04 Update myArduino.py
    Added blinking status led support
2022-04-13 Update of 3d models and first recording script
    Now the first recording script is working!
    [parametrized-3walls_v0_bad.stl, parametrized-door.stl, parametrized-tapa_alvium_v1.stl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]
2022-05-19 Update to 3d model stl files
    [parametrized-3walls_v0_bad.stl, parametrized-3walls_v1.stl, parametrized-door.stl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]
2022-06-09 Large update for first_recording data
    [parametrized-4walls_30mm.stl, parametrized.FCStd]
2022-06-16 myCamera update
    To show a crossbar during the preview
    [arenas-2-decision_making.stl, arenas.FCStd]
2022-06-21 Arduino executable file
    I created an arduino executable file that just turns the lights on. I also modified both myArduTracker and myArduino to find_arduinos()
2022-06-30 Global update
    New folders old, tests and docs.
    pytracker now tends towards becoming a module
    analysis is now in the main folder
    [arenas-2-decision_making.stl, arenas.FCStd, base_lighting.stl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]
2022-07-19 Analysis update
    [parametrized-4walls.stl, parametrized-4walls_45mm.stl]
2022-11-20 Major update:
    - Now preview shows burnt pixels (low and high-end)
    - When computing the expected position of a worm (Kalman filter) now I added a term for inertia to account for previous speeds.
    - During s3_Tracking now I only show the 100 latest positions of worms to avoid crowding the frame with trajectories.
    [myCamera_Alvium.py, myCamera_UVC.py, video_utils.py]
2023-01-23 Worm coordinates export solved
    [old_s1_Blob_extraction.py]
2023-09-13 Quickfix px to mm
    HoughCircles return the radius of the circle, while the PLATE_DIAM considers the diameters, thus a factor of 2 was missing.
